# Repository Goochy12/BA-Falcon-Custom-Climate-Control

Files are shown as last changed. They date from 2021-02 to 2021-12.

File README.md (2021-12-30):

# BA Falcon Custom Climate Control
 
## Description
This project was designed for and based on a 2003 BA Falcon with a Single Zone MCC (Manual Climate Control). An Arduino Uno and MCP2515 Can Bus Sheild were used for CAN communication with the vehicle, while an Android App (Java) was written for communication with the Arduino.

Scroll down for photos and video.

## Photos
Starting Up

https://user-images.githubusercontent.com/18386188/147720307-97b063c7-28f7-43fa-a705-af794f92d567.mp4

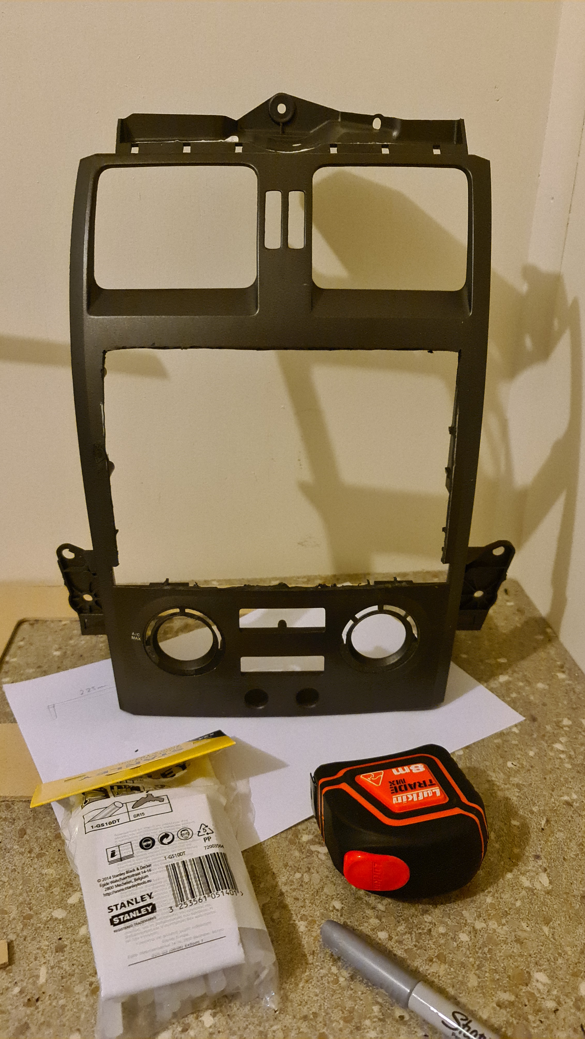
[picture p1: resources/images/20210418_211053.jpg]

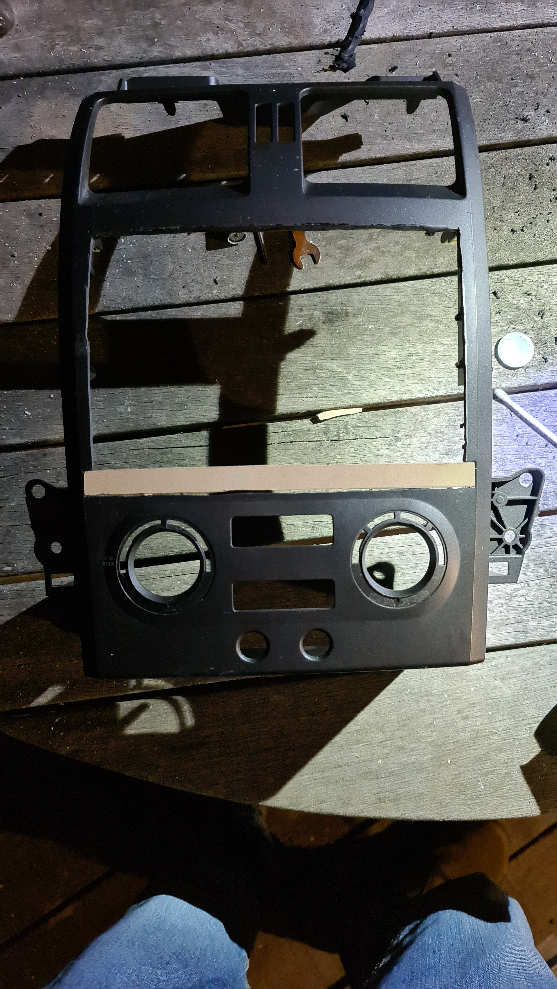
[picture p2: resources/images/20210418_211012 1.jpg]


## Credit

[Ben Hall](https://www.facebook.com/groups/208350963127229) (Used for structure of Arduino code and project objectives)

[jakka351](https://github.com/jakka351/FG-Falcon/blob/master/resources/software/arduino/ICC_CAN_Interface.ino) (Used to help solve sending CAN codes every 500ms using Simple Timer)

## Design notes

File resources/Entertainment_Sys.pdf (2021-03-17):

41s-00.00.1 | Entertainment System | 415.00.00.1

_l

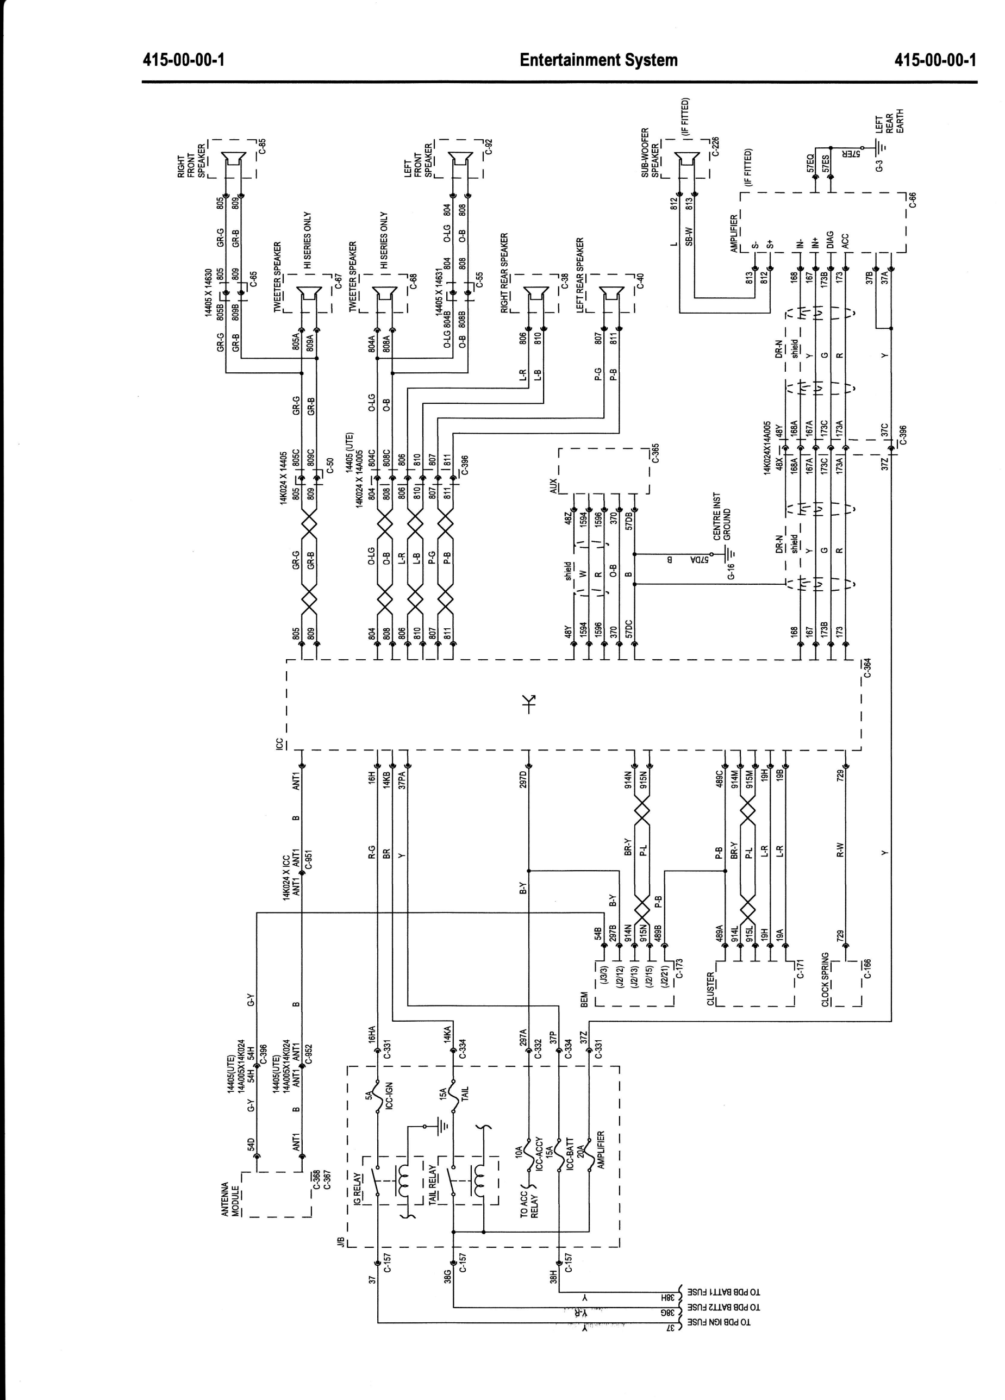
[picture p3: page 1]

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
--@ r9o

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
eutt)

I

E
A ,;P#l t | hlbl | o
[ | ++

# :-_ _ _ 1l-

frt Er
=l | (,,, a,+:i{6 =:fi- jji"r

# -+ i:l .fF[f

| | .[

# ui*i-l"l"l :

# .=lfiLll S:+-+'lj-lil- -'

# E*Lt-TJ=f - -'

| ="1.ff[t,

# r Ei*i-l"l"l

| pF Ft,
| ILtI
| _ 1=l-11-r$

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
## al- uY. sl L

ur t-

o
@
x
o

eE
*o
GT=d

F@z
ieot=

### z.o UEoo

G, ul Y
U
e
a.-
e.l
Hul

u.l I
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
- | - | -.-J

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
JIol_

I
_l
E. U. FI at
=()L

Q3

### cru FE

T
r'
t_

5U&
e

lsnj lllv8 €0d oI
tsnl zrwE 80d or
3sru Net 80d or

o@
(,
+
o
a

@

:-

### >( rt gL*-

e
ul Y
U
a
6-- tlu' Ful UI

FL

F
I
o
J | r6N
I | | l@6
I | to6 5q'. | ,o o
211 | I
u=r
?Er

!9r
-L | _

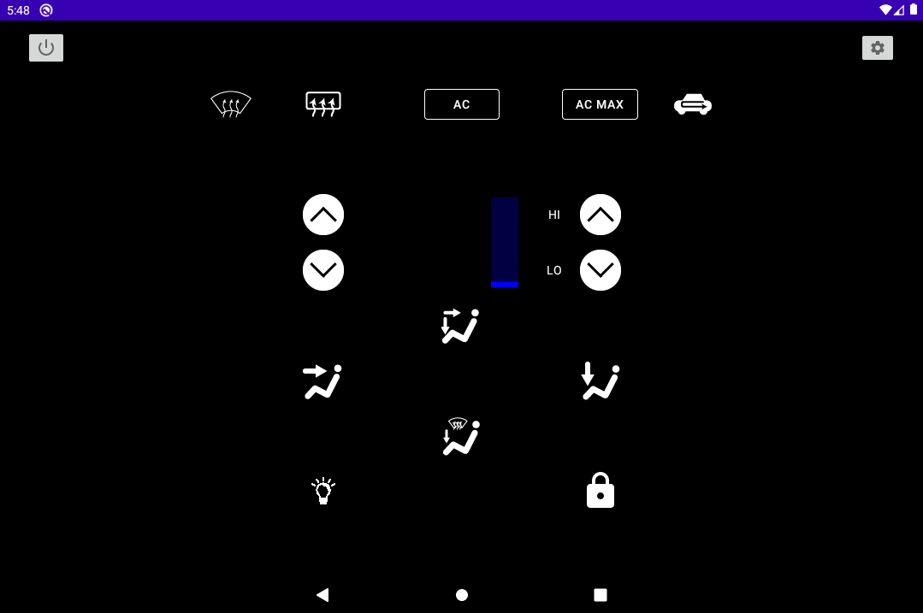
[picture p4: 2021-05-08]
Android App/assets/PlayStore/emu_screen1.png

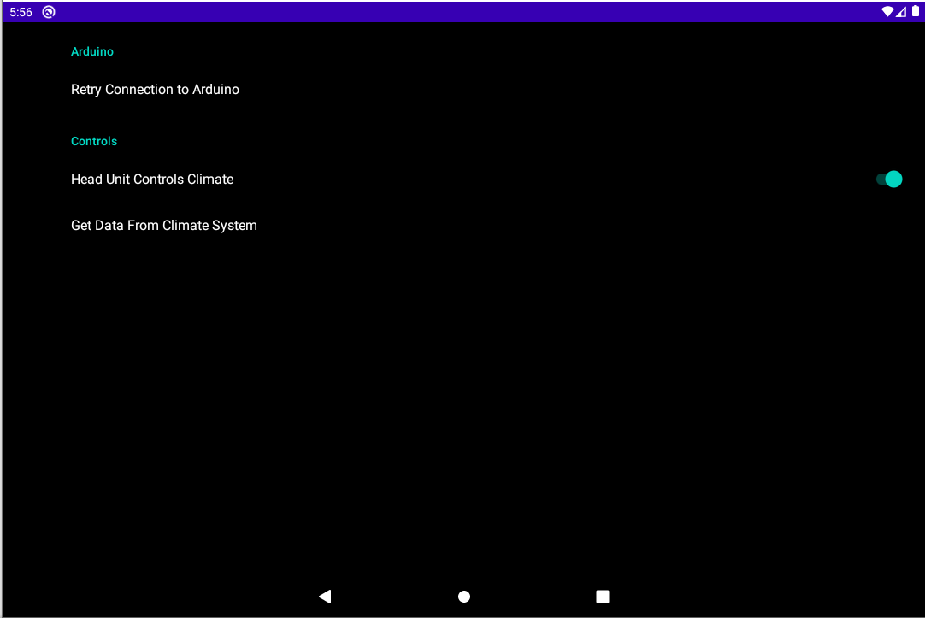
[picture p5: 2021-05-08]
Android App/assets/PlayStore/emu_screen2.png

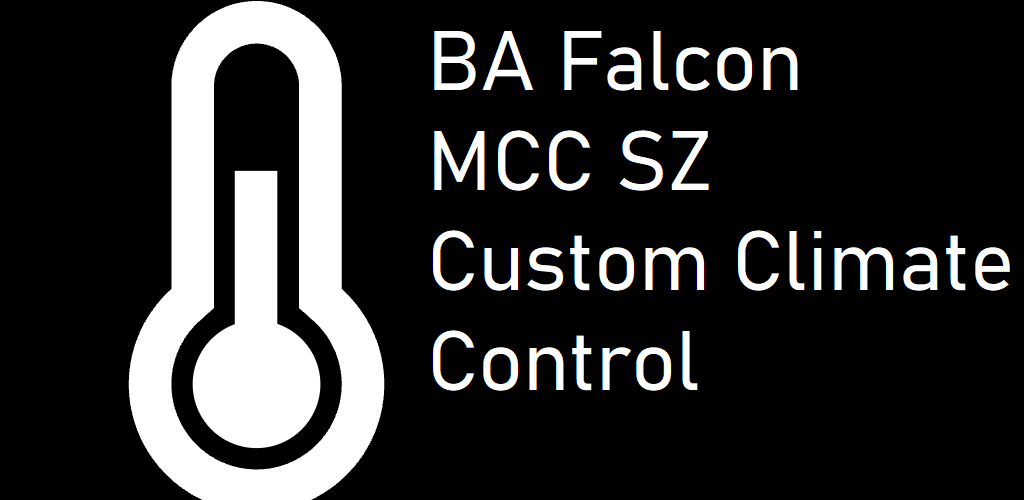
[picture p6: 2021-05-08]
Android App/assets/PlayStore/feature_image.png

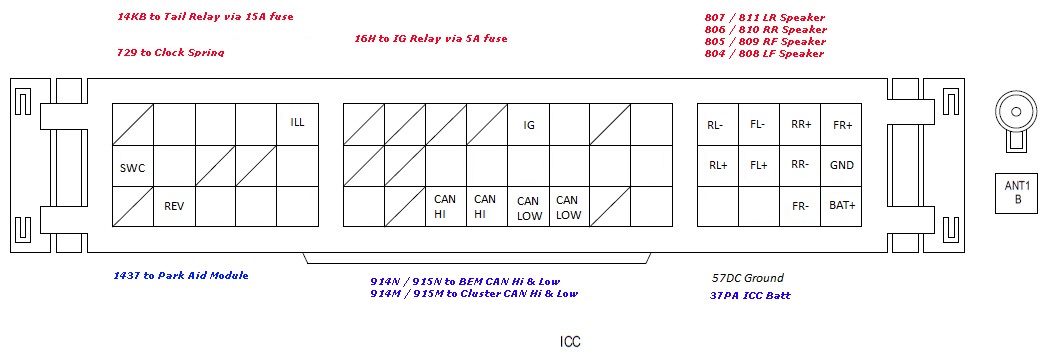
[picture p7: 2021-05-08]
resources/used_ICC_plugs.jpg

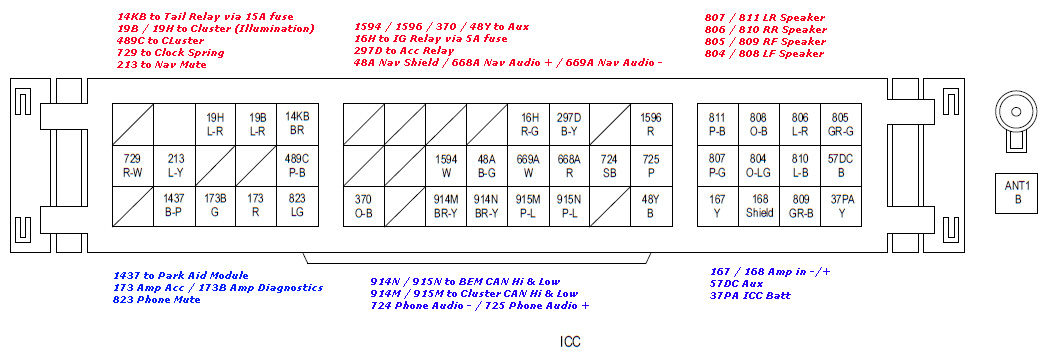
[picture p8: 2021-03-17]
resources/BAICC_C364.jpg

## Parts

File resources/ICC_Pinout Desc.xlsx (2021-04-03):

Name | Position | Input/Output | Description | Required/Optional | Replicate the Connection | Certain
Tail Relay (via 15A fuse) | 14KB | Input | Ground for illumination (ie. when taillights are on) | Optional | NA / input | Unsure
Cluster (illumination) | 19B/19H | Input | Illumination for cluster | Optional | NA / input | No Idea
Cluster | 489C | UNSURE | Global CAN BUS wake up | UNSURE
Clock Spring | 729 | Input | Steering wheel controls (SWC) | Optional | NA / input
Nav Mute | 213 | Input | To swap between current sound and navigation, when audio fitted | Optional | NA / input
Aux | 1594/1596/370/48Y | Input | 6 pin connector, FL FR RL RR GND and loop bridge | Optional | NA / input
IG (Ignition) Relay (via 5A fuse) | 16H | Input | 12v when key is in ignition position | Optional | NA / input
ACC (Accessories) Relay | 297D | Input | 12v when key is in acc position | Optional | NA / input
LR Speaker | 807/811 | Output | Speaker out | Optional | Send audio signal through direct wiring
RR Speaker | 806/810 | Output | Speaker out | Optional | Send audio signal through direct wiring
RF Speaker | 805/809 | Output | Speaker out | Optional | Send audio signal through direct wiring
LF Speaker | 804/808 | Output | Speaker out | Optional | Send audio signal through direct wiring
Park Aid Module | 1437 | Input | Parking sensor | Optional | NA / input
Amp Acc / Amp Diagnostics | 173/173B | Output | Possibly sends diagnostic codes??? | Optional | NA / input
Phone Mute | 823 | Input | Goes to 4 pin connector, 12V constant, 12V acc, phone mute, ground | Optional | NA / input
BEM CAN Hi & Low | 914N/915N | Input/Output | CAN BUS System | Required | Decode input / send appropriate output
Cluster CAN Hi & Low | 914M/915M | Input/Output | CAN BUS System | Required | Decode input / send appropriate output
Phone Audio -+ | 724/725 | Input | Goes to 2 pin connector +- audio signal | Optional | NA / input
Amp in -+ | 167/168 | Input | signal input to amp +- | Optional | NA / input
Aux | 57DC | Input | Ground | Optional | NA / input
ICC Bat | 37PA | Input | Power to the ICC | Optional | NA / input

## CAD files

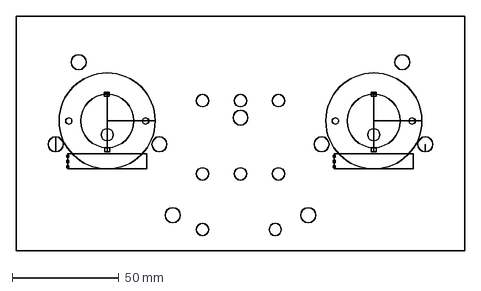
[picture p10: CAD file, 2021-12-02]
Arduino Code/pcb_outline.dxf
210.0 x 110.0 mm

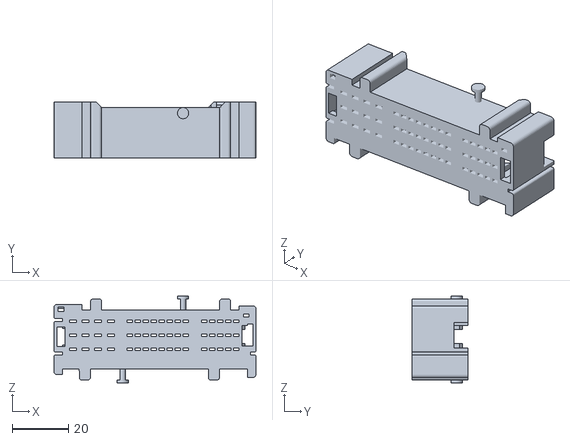
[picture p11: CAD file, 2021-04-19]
resources/ICC Plug.stl
72.0 x 20.0 x 31.0

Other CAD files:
resources/ICC Plug v2 v21.f3d

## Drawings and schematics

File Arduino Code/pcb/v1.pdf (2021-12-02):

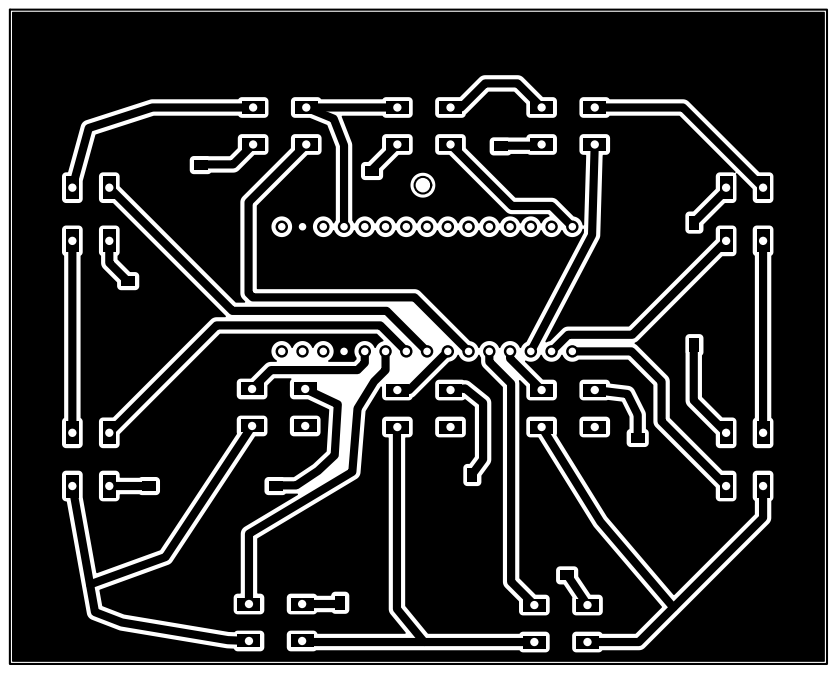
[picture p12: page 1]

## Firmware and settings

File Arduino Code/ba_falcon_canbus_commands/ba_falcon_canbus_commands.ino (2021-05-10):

//#include <mcp_can.h>
#include <SPI.h>
#include "mcp2515_can.h"
#include <SimpleTimer.h>

const int SPI_CS_PIN = 10; //pin 10 on arduino
const int CAN_INT_PIN = 2; //interrupt pin on arduino

const int buttonID = 0x307; //button press ID
const int himID = 0x353;    //HIM ID
const int bemID = 0x403;    //BEM ID
const int tempID = 0x001;   //temp ID
const int fanID = 0x002;    //fan ID

const unsigned char keepAliveID = 0x80;                           //keep alive ID byte 3
const unsigned char KeepAlive[8] = {0, 0, 0, 0x80, 0, 1, 0, 0xA}; //standard keep alive array
unsigned char BEM[8] = {0, 0, 0, 0, 0, 0, 0, 0};                  //standard BEM CAN array
unsigned char HIM[8] = {0, 0, 0, 0, 0, 0, 0, 0};                  //standard HIM CAN array

mcp2515_can CAN(SPI_CS_PIN); //set the CAN CS pin

unsigned char ICC_Buttons[8] = {0, 0, 0, 0x80, 0, 8, 0, 0xA};  //mutable keep alive array
unsigned char ICC_Buttons_OFF[8] = {0, 0, 0, 0, 0, 0, 0, 0xA}; //mutable keep alive array (car off)

//fan and temp settings
int fanValue = 0x0; //current fan value
int fanMax = 0xE;   //max fan value
int fanMin = 0x0;   //min fan value

int tempValue = 0x8; //current temp value
int tempMax = 0xE;   //max temp value
int tempMin = 0x0;   //min temp value

SimpleTimer timer100ms; //sleep timer that runs every 100ms

//Serial input parameters
const char startChar = '<'; //start char for serial input
const char endChar = '>';   //start char
char incomingSerial[32];    //serial input buffer
int incomingCount = 0;      //current char from serial input
bool reading = false;       //currently reading serial input flag
int sendButton = 0;         //send button press flag
bool climateOff = false;    //climate on/off flag
int keyCoding = 0;         //flag for coding key remotes to the central locking module

const String errorString = "error"; //error string

void setup()
{
  Serial.begin(115200); //begin serial with 115200 baud rate

  //initialise CAN
  while (!start())
    ;

  timer100ms.setInterval(100, incTimer); //run the incTimer method every 100ms
}

void loop()
{
  timer100ms.run();
  //get serial in and process
  if (Serial.available())
  {
    processSerialIn();
  }

  if (sendButton >= 5)
  {
    if (keyCoding >= 1)
    {
      //if key coding active
      rearDemist(); //set rear demist button
      keyCoding++;  //increment the key coding
      if (keyCoding > 3)
      {
        keyCoding = 0; //cap variable at 3 and reset once reached
      }
    }
    if (!climateOff)
    {
      sendButtonPressed(); //send the ICC keep alive CAN message
      resetICCButton();    //reset the ICC keep alive CAN array
      sendButton = 0;      //reset the button press flag
    }
  }

  //process CAN data (from car)
  if (CAN_MSGAVAIL == CAN.checkReceive())
  {                                   //check data incoming
    unsigned char len = 0;            //length of the CAN message
    unsigned char buf[8];             //CAN message
    CAN.readMsgBuf(&len, buf);        //read data: length and buffer (data)
    int canNodeID = CAN.getCanId();   //get the CAN ID
    processCANDataIn(canNodeID, buf); //process the incoming CAN data
  }
}

/*
Function to start the CAN transceiver
*/
boolean start()
{
  //if CAN wiring OK - run the CAN BUS at 500KBPS
  if (CAN_OK != CAN.begin(CAN_500KBPS))
  {
    Serial.println("FAIL");
    delay(100);
    return false;
  }
  else
  {
    Serial.println("START");
    return true;
  }
}

/*
Function to increment the sendButton flag
*/
void incTimer()
{
  sendButton++;
}

/*
Function to send a CAN message (to the car)
*/
void sendCANMessage(int id, unsigned char msg[8])
{
  //sendMsgBuf(id (hex), 0, 8, data buf)
  CAN.sendMsgBuf(id, 0, 8, msg);
}

/*Function to send a serial message*/
void sendSerialData(unsigned long ID, unsigned char msg)
{
  String sM; //construct a string
  sM = "<CAN_MSG: " + String(ID, HEX) + " " + String(msg, HEX) + ">";
  Serial.println(sM); //print to serial
}

/*
Function to process the serial data received
*/
void processSerialIn()
{
  char sIn = Serial.read(); //read the current character
  //if the character is an end character and currently reading a string
  if (sIn == endChar && reading)
  {
    actionSerialIn(incomingSerial); //send the serial input to be processed and actioned

    //reset incoming serial
    reading = false;
    for (int i; i < incomingCount; i++)
    {
      incomingSerial[i] = (char)0; //reset incoming serial at i
    }
    incomingCount = 0; //reset the count
  }
  else if (sIn == startChar)
  {
    //if start serial in
    reading = true;
  }
  else if (reading)
  {
    //if currently reading serial
    incomingSerial[incomingCount] = sIn; //add the character to the char array
    incomingCount++;                     //increment the counter
  }
}

/*
Method to process use an ICC function
TODO: use variables
*/
void actionSerialIn(char sIn[32])
{
  if (strcmp(sIn, "door_lock") == 0)
  {
    doorLock();
  }
  else if (strcmp(sIn, "dome_light") == 0)
  {
    domeLight();
  }
  else if (strcmp(sIn, "cabin_cycle") == 0)
  {
    cabin_cycle();
  }
  else if (strcmp(sIn, "rear_demist") == 0)
  {
    rearDemist();
  }
  else if (strcmp(sIn, "feet_front_demist") == 0)
  {
    feetFrontDemist();
  }
  else if (strcmp(sIn, "front_demist") == 0)
  {
    frontDemist();
  }
  else if (strcmp(sIn, "face") == 0)
  {
    face();
  }
  else if (strcmp(sIn, "feet") == 0)
  {
    feet();
  }
  else if (strcmp(sIn, "face_feet") == 0)
  {
    faceFeet();
  }
  else if (strcmp(sIn, "ac") == 0)
  {
    ac();
  }
  else if (strcmp(sIn, "fan_up") == 0)
  {
    fanUp();
  }
  else if (strcmp(sIn, "fan_down") == 0)
  {
    fanDown();
  }
  else if (strcmp(sIn, "temp_up") == 0)
  {
    tempUp();
  }
  else if (strcmp(sIn, "temp_down") == 0)
  {
    tempDown();
  }
  else if (strcmp(sIn, "temp0") == 0)
  {
    temp0();
  }
  else if (strcmp(sIn, "get_data") == 0)
  {
    sendData();
  }
  else if (strcmp(sIn, "climate_off") == 0)
  {
    climateOff = true;
  }
  else if (strcmp(sIn, "climate_on") == 0)
  {
    climateOff = false;
  }
  else if (strcmp(sIn, "key_code") == 0)
  {
    keyCoding = 1;
  }
  return;
}

/*
Function to process CAN data received from the Car
*/
void processCANDataIn(unsigned long canNodeID, unsigned char buf[8])
{
  //TODO Update IF statements - code smells: add to array
  //read CAN ID
  // String code;
  bool dataChanged = false; //has the data changed flag
  //if the CAN ID is equal to the HIM ID
  if (canNodeID == himID)
  {
    //check whether the important data has changed
    if (HIM[0] != buf[0])
    {
      dataChanged = true; //set the data changed flag
    }
    for (int i = 0; i < 8; i++)
    {
      HIM[i] = buf[i]; //update the data
    }
  }
  //if the CAN ID is equal to the BEM ID
  else if (canNodeID == bemID)
  {
    //check whether the important data has changed
    if (BEM[0] != buf[0])
    {
      dataChanged = true; //set the data changed flag
    }
    for (int i = 0; i < 8; i++)
    {
      BEM[i] = buf[i]; //update the data
    }
  }

  if (dataChanged)
  {
    //if the data has changed, send it via serial
    sendData();
  }
  dataChanged = false; //reset the flag
}

/*
Function to set the ICC button array to a certain value at a particular position
*/
void setICCButton(int position, int code)
{
  ICC_Buttons[position] = code; //set the code at a position
}

/*
Function to reset the keep alive array to default (with fan and temp)
*/
void resetICCButton()
{
  for (int i = 0; i < sizeof(KeepAlive); i++)
  {
    ICC_Buttons[i] = KeepAlive[i]; //reset to the static keep alive array
  }
  //temp and fan positions
  iccTemp();
  iccFan();
}

/*
Function to send a CAN message via button press
*/
void sendButtonPressed()
{
  sendCANMessage(buttonID, ICC_Buttons);
}

void doorLock()
{
  setICCButton(3, 0xC0);
}

void doorLock_OFF()
{
  setICCButton(3, 0x40);
}

void domeLight()
{
  setICCButton(3, 0xA0);
}

void domeLight_OFF()
{
  setICCButton(3, 0x20);
}

void cabin_cycle()
{
  setICCButton(0, 0x40);
}

void rearDemist()
{
  setICCButton(0, 0x20);
}

void feetFrontDemist()
{
  setICCButton(0, 0x1);
}

void frontDemist()
{
  setICCButton(0, 0x2);
}

void face()
{
  setICCButton(0, 0x10);
}

void faceFeet()
{
  setICCButton(0, 0x4);
}

void feet()
{
  setICCButton(0, 0x8);
}

void ac()
{
  setICCButton(0, 0x80);
}

void fanUp()
{
  if (fanValue < fanMax)
  {
    //if the fan is less than the max fan value
    fanValue += 0x1; //increment the fan value
    iccFan();        //set the fan value in the array
  }
}

void fanDown()
{
  if (fanValue > fanMin)
  {
    //if the fan is greater than the min fan value
    fanValue -= 0x1; //decrement the fan value
    iccFan();        //set the fan value in the array
  }
}

void tempUp()
{
  if (tempValue < tempMax)
  {
    //if the temp is less than the max temp value
    tempValue += 0x1; //increment the temp value
    iccTemp();        //set the temp value in the array
  }
}

void tempDown()
{
  if (tempValue > tempMin)
  {
    //if the temp is greater than the min temp value
    tempValue -= 0x1; //decrement the temp value
    iccTemp();        //set the temp value in the array
  }
}

/*
Function to set the temp to 0
*/
void temp0()
{
  tempValue = 0x0;
  iccTemp();
}

/*
Function to send the BEM and HIM data via serial
*/
void sendData()
{
  sendSerialData(bemID, BEM[0]);          //send BEM data
  sendSerialData(himID, HIM[0]);          //send HIM data
  sendSerialData(tempID, ICC_Buttons[5]); //send temp data
  sendSerialData(fanID, ICC_Buttons[6]);  //send fan data
}

//TODO: UPDATE METHODS WITH INPUT FROM KNOBS
void iccTemp()
{
  setICCButton(5, tempValue);
}

void iccFan()
{
  setICCButton(6, fanValue);
}

void setTemp(int tempV)
{
  tempValue = tempV;
}

void setFan(int fanV)
{
  fanValue = fanV;
}

//MAPPINGS
// const unsigned char acOpenFace = 0xB2;
// const unsigned char acOpenFeet = 0xAA;
// const unsigned char acOpenFaceFeet = 0xBA;
// const unsigned char acOpenFrontDemist = 0xA6;
// const unsigned char acOpenFeetFrontDemist = 0xAE;
// const unsigned char acClosedFace = 0xD2;
// const unsigned char acClosedFeet = 0xCA;
// const unsigned char acClosedFaceFeet = 0xDA;
// const unsigned char acClosedFrontDemist = 0xC6;
// const unsigned char acClosedFeetFrontDemist = 0xCE;
// const unsigned char openFace = 0x32;
// const unsigned char openFeet = 0x2A;
// const unsigned char openFaceFeet = 0x3A;
// const unsigned char openFrontDemist = 0x26;
// const unsigned char openFeetFrontDemist = 0x2E;
// const unsigned char closedFace = 0x52;
// const unsigned char closedFeet = 0x4A;
// const unsigned char closedFaceFeet = 0x5A;
// const unsigned char closedFeetFrontDemist = 0x4E;

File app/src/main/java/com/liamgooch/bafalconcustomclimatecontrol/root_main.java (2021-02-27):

package com.liamgooch.bafalconcustomclimatecontrol;

import android.app.Activity;
import android.content.Context;
import android.graphics.Color;
import android.graphics.PorterDuff;
import android.os.Bundle;

import androidx.annotation.NonNull;
import androidx.fragment.app.Fragment;

import android.util.Log;
import android.view.LayoutInflater;
import android.view.View;
import android.view.ViewGroup;
import android.widget.Button;
import android.widget.ImageButton;
import android.widget.ProgressBar;
import android.widget.Toast;

public class root_main extends Fragment implements USBSerialCallbacks {

    private static final String TAG = "BAFalcon-Test";
    private static final String ac_string = "ac";
    private static final String fan_up_string = "fan_up";
    private static final String fan_down_string = "fan_down";
    private static final String temp_up_string = "temp_up";
    private static final String temp_down_string = "temp_down";
    private static final String face_string = "face";
    private static final String feet_string = "feet";
    private static final String front_demist_string = "front_demist";
    private static final String rear_demist_string = "rear_demist";
    private static final String closed_cabin_string = "closed_cabin";
    private static final String open_cabin_string = "open_cabin";
    private static final String cabin_cycle_string = "cabin_cycle";
    private static final String dome_light_string = "dome_light";
    private static final String door_lock_string = "door_lock";

    private UsbSerial usbSerial;

    private ImageButton button_frontDemist, button_rearDemist, button_cabin_cycle, button_fanUp,
            button_fanDown, button_tempUp, button_tempDown, button_domeLight, button_doorLock, button_settings;

    private Button button_ac, button_acMax;

    //boolean variables for button
    private Boolean button_frontDemist_isSelected, button_rearDemist_isSelected, button_cabin_cycle_isSelected, button_ac_isSelected, button_acMax_isSelected;

    private ProgressBar fanProgressBar, tempProgressBar;

    private Activity thisActivity;
    private Context thisContext;

    public root_main() {
        // Required empty public constructor
    }

    @Override
    public void onCreate(Bundle savedInstanceState) {
        super.onCreate(savedInstanceState);
        this.thisActivity = getActivity();
        this.thisContext = getContext();
    }

    @Override
    public View onCreateView(LayoutInflater inflater, ViewGroup container,
                             Bundle savedInstanceState) {
        // Inflate the layout for this fragment
        return inflater.inflate(R.layout.fragment_root_main, container, false);
    }

    @Override
    public void onViewCreated(@NonNull View view, Bundle savedInstanceState) {
        //declare buttons
        button_settings = view.findViewById(R.id.settings_button);

        button_frontDemist = view.findViewById(R.id.button_frontDemist);
        button_rearDemist = view.findViewById(R.id.button_rearDemist);
        button_cabin_cycle = view.findViewById(R.id.button_cabin_cycle);
        button_fanUp = view.findViewById(R.id.button_fanUp);
        button_fanDown = view.findViewById(R.id.button_fanDown);
        button_tempUp = view.findViewById(R.id.button_tempUp);
        button_tempDown = view.findViewById(R.id.button_tempDown);
        button_domeLight = view.findViewById(R.id.button_domeLight);
        button_doorLock = view.findViewById(R.id.button_doorLock);

        button_ac = view.findViewById(R.id.button_ac);
        button_acMax = view.findViewById(R.id.button_acMax);

        //declare progress bars
        fanProgressBar = (ProgressBar) view.findViewById(R.id.fanProgressBar);
        tempProgressBar = (ProgressBar) view.findViewById(R.id.tempProgressBar);

        //set boolean variables
        button_frontDemist_isSelected = false;
        button_rearDemist_isSelected = false;
        button_cabin_cycle_isSelected = false;
        button_ac_isSelected = false;
        button_acMax_isSelected = false;

        button_settings = view.findViewById(R.id.settings_button);
        //declare button listeners

        button_settings.setOnClickListener(new View.OnClickListener() {
            @Override
            public void onClick(View v) {
                getParentFragmentManager().beginTransaction().replace(R.id.fragment_container, new SettingsFragment()).addToBackStack("settings").commit();
            }
        });

        button_ac.setOnClickListener(new View.OnClickListener() {
            @Override
            public void onClick(View v) {
                sendAC_status();
                setAC(!getButton_ac_isSelected());
            }
        });

        button_acMax.setOnClickListener(new View.OnClickListener() {
            @Override
            public void onClick(View v) {
                setAcMax(!getButton_acMax_isSelected());
                if(getButton_acMax_isSelected()){
                    setTempProgressBar(0);
                }else {
                    setTempProgressBar(1);
                }
            }
        });

        button_frontDemist.setOnClickListener(new View.OnClickListener() {
            @Override
            public void onClick(View v) {
                sendfrontDemist_status();
                setfrontDemist(!getButton_frontDemist_isSelected());
            }
        });

        button_rearDemist.setOnClickListener(new View.OnClickListener() {
            @Override
            public void onClick(View v) {
                sendRearDemist_status();
                setRearDemist(!getButton_rearDemist_isSelected());
            }
        });

        button_cabin_cycle.setOnClickListener(new View.OnClickListener() {
            @Override
            public void onClick(View v) {
                sendCabinCycle_status();
                setCabinCycle(!getButton_cabin_cycle_isSelected());
            }
        });

        button_fanUp.setOnClickListener(new View.OnClickListener() {
            @Override
            public void onClick(View v) {
                incrementFanProgressBar(1);
                sendFanUp_status();
            }
        });

        button_fanDown.setOnClickListener(new View.OnClickListener() {
            @Override
            public void onClick(View v) {
                incrementFanProgressBar(-1);
                sendFanDown_status();
            }
        });

        button_tempUp.setOnClickListener(new View.OnClickListener() {
            @Override
            public void onClick(View v) {
                incrementTempProgressBar(1);
                sendtempUp_status();
            }
        });

        button_tempDown.setOnClickListener(new View.OnClickListener() {
            @Override
            public void onClick(View v) {
                incrementTempProgressBar(-1);
                sendtempDown_status();
            }
        });
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

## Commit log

2020-11-25 add ac buttons
2020-11-25 add buttons
2020-11-25 remove background from image buttons
2020-11-28 add buttons and on click listeners
2020-11-28 update button colours
2020-11-28 add button click variables
2020-11-28 apply colour switching on button presses
2021-01-31 add canbus init
2021-02-18 update button presses and serial output
2021-02-21 add button press methods
2021-02-24 add button methods
2021-02-24 add fan and temp modifiers
2021-02-26 update buttons
2021-02-27 add settings button
2021-02-27 add settings button asset
2021-02-28 add climate buttons
2021-03-05 set button actions from serial
2021-03-17 add resources
    [decodedPackets.xlsx]
2021-03-17 rename to resources
    [decodedPackets.xlsx]
2021-03-18 fixed const char to mutable
    [ba_falcon_canbus_commands.ino]
2021-03-19 add simple timer and test prints
2021-03-21 fix AC button issues
2021-03-21 update switch statement to only update buttons and not resend status
2021-03-23 add run timer and remove test serial prints
2021-03-27 Create ICC_Pinout Desc.xlsx
    [ICC_Pinout Desc.xlsx]
2021-03-27 Update ICC_Pinout Desc.xlsx
    [ICC_Pinout Desc.xlsx]
2021-04-03 send temp and fan values
2021-04-03 add temp and fan IDs
2021-04-03 refactor processor and add temp and fan
2021-04-03 add set fan
2021-04-03 fix demist button and add on resume get data
2021-04-05 add button update before serial confirm and disable deselect of button
2021-04-12 Create ICC Plug v2 v21.f3d
    [ICC Plug v2 v21.f3d]
2021-04-19 Create ICC Plug.stl
    [ICC Plug.stl]
2021-04-24 add off button
2021-04-24 add on button functionality
2021-09-10 add pcb files
    [pcb_design.fzz, pcb_design2.fzz]
2021-09-10 one sided pcb
    [pcb_design_one_sided.fzz]
